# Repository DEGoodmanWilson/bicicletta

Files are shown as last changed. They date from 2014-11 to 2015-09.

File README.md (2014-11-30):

BICICLETTA
==========

Bicicletta is an open source iOS / Android interface for your electric bicycle.

You can read more about this project on the project's [Github Page](http://degoodmanwilson.github.io/bicicletta/)

FIRMWARE LICENSE
================

Copyright © D.E. Goodman-Wilson 2014.

Bicicletta Firmware is free software: you can redistribute it and/or modify
it under the terms of the GNU General Public License as published by
the Free Software Foundation, either version 3 of the License, or
(at your option) any later version.

This program is distributed in the hope that it will be useful,
but WITHOUT ANY WARRANTY; without even the implied warranty of
MERCHANTABILITY or FITNESS FOR A PARTICULAR PURPOSE.  See the
GNU General Public License for more details.

You should have received a copy of the GNU General Public License
along with Bicicletta Firmware.  If not, see <http://www.gnu.org/licenses/>.

The full text of the license is available in /firmware/LICENSE.txt

HARDWARE LICENSE
================

Copyright © D.E. Goodman-Wilson 2014.

This documentation describes Open Hardware and is licensed under the
CERN OHL v. 1.2.

You may redistribute and modify this documentation under the terms of the
CERN OHL v.1.2. (http://ohwr.org/cernohl). This documentation is distributed
WITHOUT ANY EXPRESS OR IMPLIED WARRANTY, INCLUDING OF
MERCHANTABILITY, SATISFACTORY QUALITY AND FITNESS FOR A
PARTICULAR PURPOSE. Please see the CERN OHL v.1.2 for applicable
conditions.

The full text of the license is available in /hardware/LICENSE.txt

You can read more about how the CERN OHL license applies to this project [on the CERN website](http://www.ohwr.org/attachments/2392/cern_ohl_v_1_2_howto.pdf).

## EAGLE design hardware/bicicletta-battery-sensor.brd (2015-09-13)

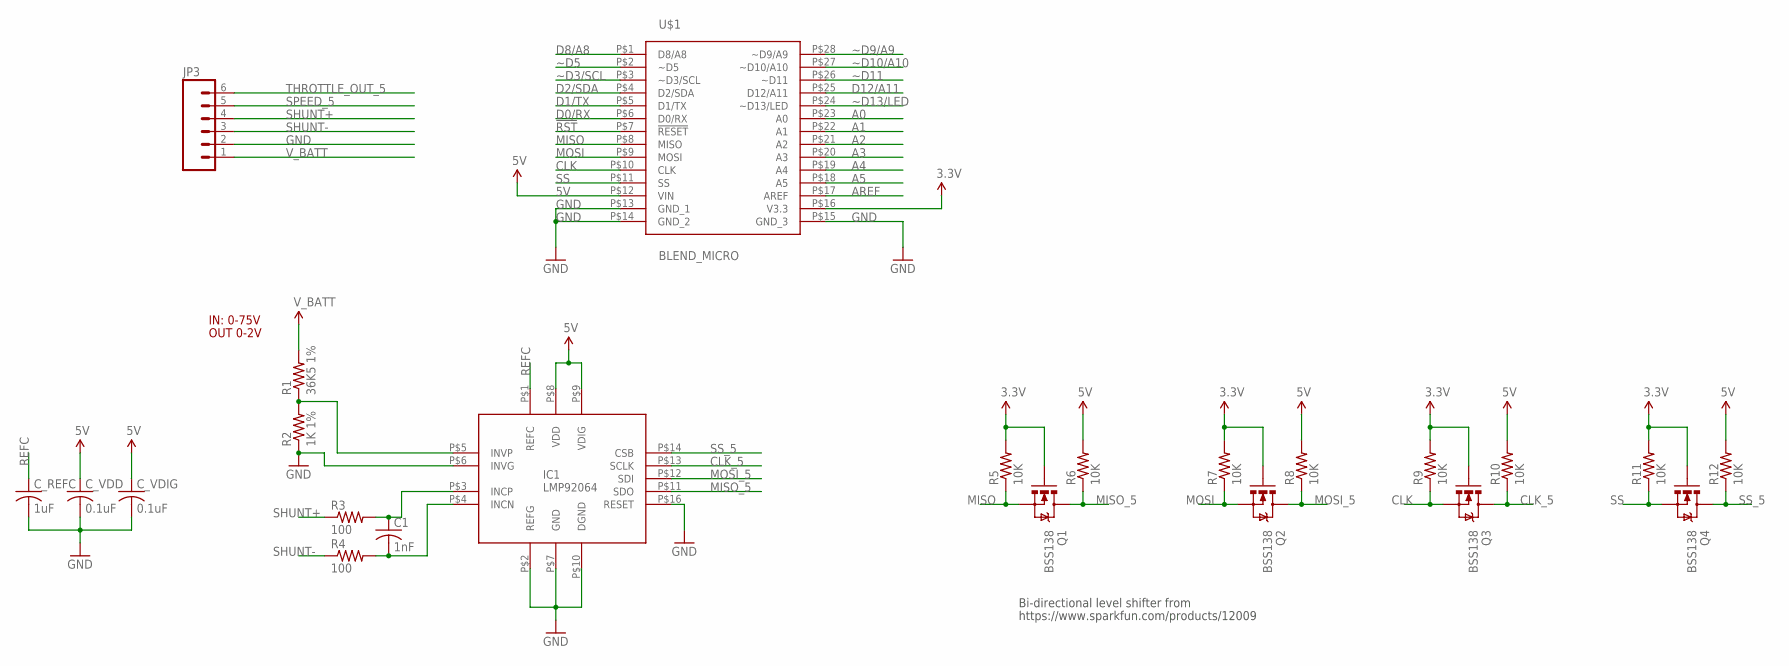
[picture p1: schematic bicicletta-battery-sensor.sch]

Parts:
C1: 1nF; C0603
C_REFC: 1uF; C0603
C_VDD: 0.1uF; C0603
C_VDIG: 0.1uF; C0603
IC1: LMP92064; WSON-16
JP3: M06SIP; 1X06
Q1, Q2, Q3, Q4: BSS138; SOT23-3
R1: 36K5 1%; R0603
R2: 1K 1%; R0603
R3, R4: 100; R0603
R5, R6, R7, R8, R9, R10, R11, R12: 10K; R0603
U$1: BLEND_MICRO

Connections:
3.3V: Q1.1 (G), Q2.1 (G), Q3.1 (G), Q4.1 (G), R5.2, R7.2, R9.2, R11.2, U$1.P$16 (V3.3)
5V: C_VDD.1, C_VDIG.1, IC1.P$8 (VDD), IC1.P$9 (VDIG), R6.2, R8.2, R10.2, R12.2, U$1.P$12 (VIN)
!RST: U$1.P$7 (!RESET)
A0: U$1.P$23 (A0)
A1: U$1.P$22 (A1)
A2: U$1.P$21 (A2)
A3: U$1.P$20 (A3)
A4: U$1.P$19 (A4)
A5: U$1.P$18 (A5)
AREF: U$1.P$17 (AREF)
CLK: Q3.2 (S), R9.1, U$1.P$10 (CLK)
CLK_5: IC1.P$13 (SCLK), Q3.3 (D), R10.1
D0/RX: U$1.P$6 (D0/RX)
D1/TX: U$1.P$5 (D1/TX)
D2/SDA: U$1.P$4 (D2/SDA)
D8/A8: U$1.P$1 (D8/A8)
D12/A11: U$1.P$25 (D12/A11)
GND: C_REFC.2, C_VDD.2, C_VDIG.2, IC1.P$2 (REFG), IC1.P$6 (INVG), IC1.P$7 (GND), IC1.P$10 (DGND), IC1.P$16 (RESET), JP3.2, R2.1, U$1.P$13 (GND_1), U$1.P$14 (GND_2), U$1.P$15 (GND_3)
MISO: Q1.2 (S), R5.1, U$1.P$8 (MISO)
MISO_5: IC1.P$11 (SDO), Q1.3 (D), R6.1
MOSI: Q2.2 (S), R7.1, U$1.P$9 (MOSI)
MOSI_5: IC1.P$12 (SDI), Q2.3 (D), R8.1
unnamed: IC1.P$5 (INVP), R1.1, R2.2
unnamed: C1.1, IC1.P$3 (INCP), R3.2
unnamed: C1.2, IC1.P$4 (INCN), R4.2
REFC: C_REFC.1, IC1.P$1 (REFC)
SHUNT+: JP3.4, R3.1
SHUNT-: JP3.3, R4.1
SPEED_5: JP3.5
SS: Q4.2 (S), R11.1, U$1.P$11 (SS)
SS_5: IC1.P$14 (CSB), Q4.3 (D), R12.1
THROTTLE_OUT_5: JP3.6
V_BATT: JP3.1, R1.2
~D3/SCL: U$1.P$3 (~D3/SCL)
~D5: U$1.P$2 (~D5)
~D9/A9: U$1.P$28 (~D9/A9)
~D10/A10: U$1.P$27 (~D10/A10)
~D11: U$1.P$26 (~D11)
~D13/LED: U$1.P$24 (~D13/LED)

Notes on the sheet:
IN: 0-75V
OUT 0-2V
Bi-directional level shifter from
https://www.sparkfun.com/products/12009

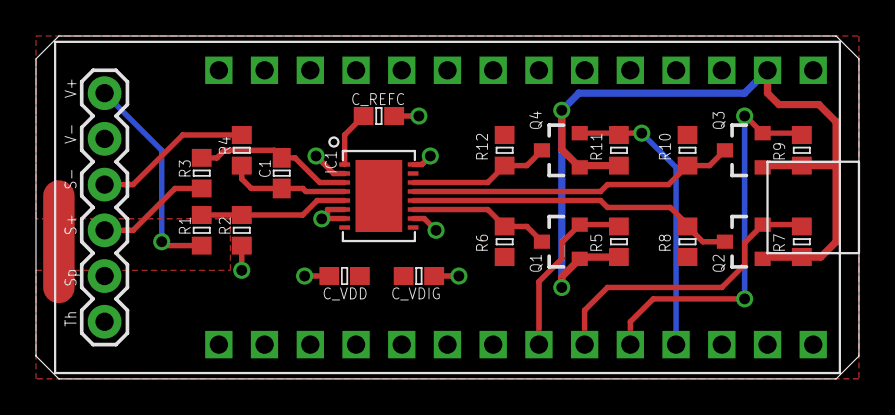
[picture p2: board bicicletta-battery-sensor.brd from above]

Board: 2 copper layers, 45.7 x 19.1 mm, 24 parts (1 on the bottom side), 18 nets.

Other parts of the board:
U$2: RAILSTARS_25MM

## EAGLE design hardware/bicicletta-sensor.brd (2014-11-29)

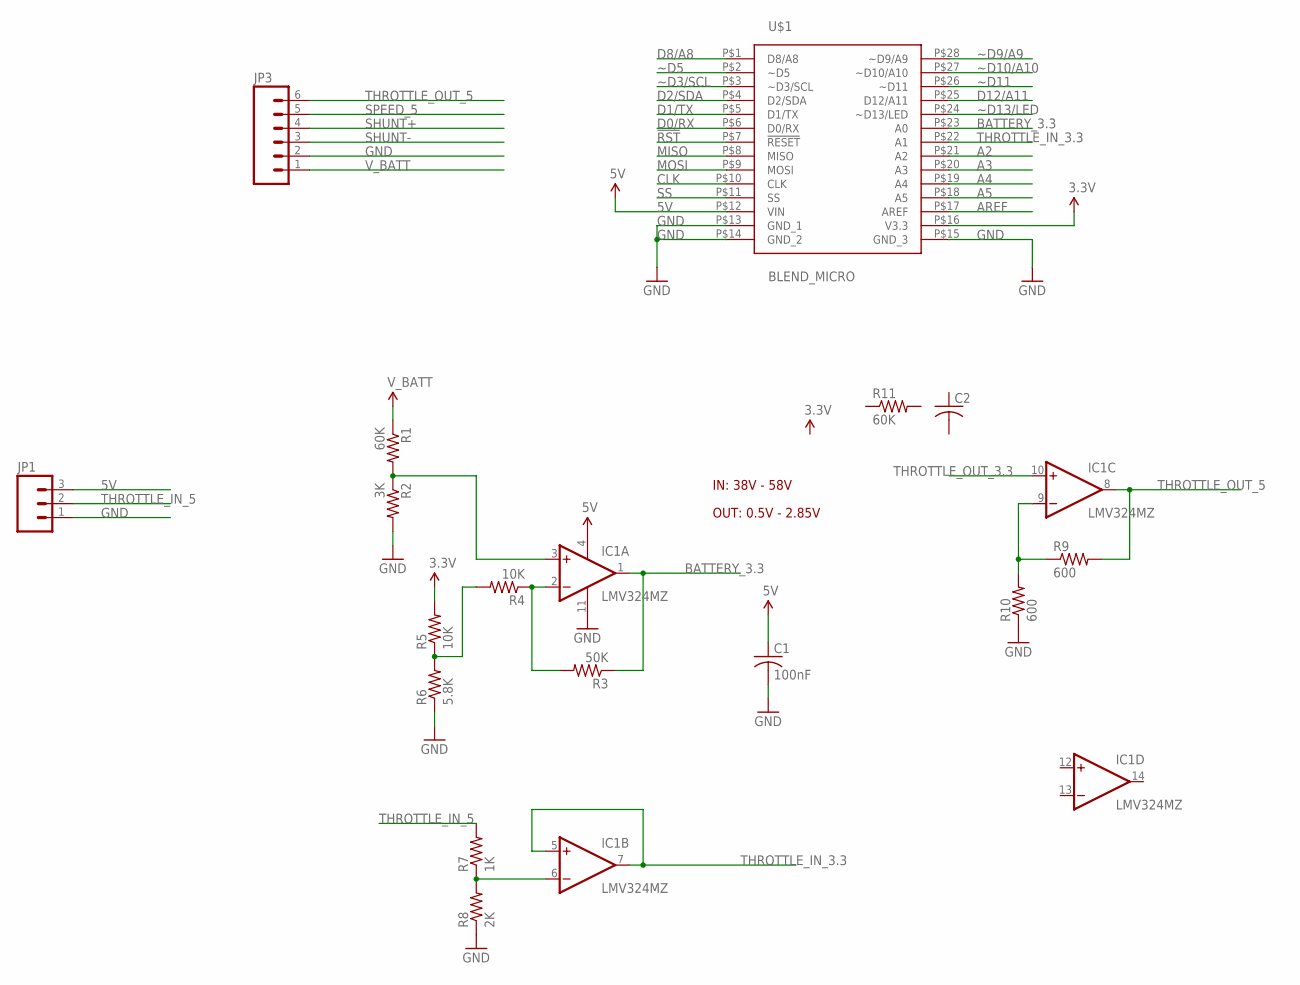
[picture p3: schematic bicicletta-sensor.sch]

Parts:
C1: 100nF; C0603
C2: C-USC0603; C0603
IC1: LMV324MZ; TSSOP14
JP1: M03PTH; 1X03
JP3: M06SIP; 1X06
R1, R11: 60K; R0603
R2: 3K; R0603
R3: 50K; R0603
R4, R5: 10K; R0603
R6: 5.8K; R0603
R7: 1K; R0603
R8: 2K; R0603
R9, R10: 600; R0603
U$1: BLEND_MICRO

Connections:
3.3V: R5.2, U$1.P$16 (V3.3)
5V: C1.1, IC1.4 (V+), JP1.3, U$1.P$12 (VIN)
!RST: U$1.P$7 (!RESET)
A2: U$1.P$21 (A2)
A3: U$1.P$20 (A3)
A4: U$1.P$19 (A4)
A5: U$1.P$18 (A5)
AREF: U$1.P$17 (AREF)
BATTERY_3.3: IC1.1 (OUT), R3.1, U$1.P$23 (A0)
BIAS: R4.2, R5.1, R6.2
CLK: U$1.P$10 (CLK)
D0/RX: U$1.P$6 (D0/RX)
D1/TX: U$1.P$5 (D1/TX)
D2/SDA: U$1.P$4 (D2/SDA)
D8/A8: U$1.P$1 (D8/A8)
D12/A11: U$1.P$25 (D12/A11)
GND: C1.2, IC1.11 (V-), JP1.1, JP3.2, R2.2, R6.1, R8.1, R10.1, U$1.P$13 (GND_1), U$1.P$14 (GND_2), U$1.P$15 (GND_3)
MISO: U$1.P$8 (MISO)
MOSI: U$1.P$9 (MOSI)
unnamed: IC1.9 (-IN), R9.1, R10.2
unnamed: IC1.3 (+IN), R1.2, R2.1
unnamed: IC1.2 (-IN), R3.2, R4.1
unnamed: IC1.6 (-IN), R7.1, R8.2
SHUNT+: JP3.4
SHUNT-: JP3.3
SPEED_5: JP3.5
SS: U$1.P$11 (SS)
THROTTLE_IN_3.3: IC1.5 (+IN), IC1.7 (OUT), U$1.P$22 (A1)
THROTTLE_IN_5: JP1.2, R7.2
THROTTLE_OUT_3.3: IC1.10 (+IN)
THROTTLE_OUT_5: IC1.8 (OUT), JP3.6, R9.2
V_BATT: JP3.1, R1.1
~D3/SCL: U$1.P$3 (~D3/SCL)
~D5: U$1.P$2 (~D5)
~D9/A9: U$1.P$28 (~D9/A9)
~D10/A10: U$1.P$27 (~D10/A10)
~D11: U$1.P$26 (~D11)
~D13/LED: U$1.P$24 (~D13/LED)

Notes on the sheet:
IN: 38V - 58V
OUT: 0.5V - 2.85V

Board: 2 copper layers, 18 parts (1 on the bottom side), 13 nets, no tracks yet.

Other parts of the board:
U$2: RAILSTARS_25MM

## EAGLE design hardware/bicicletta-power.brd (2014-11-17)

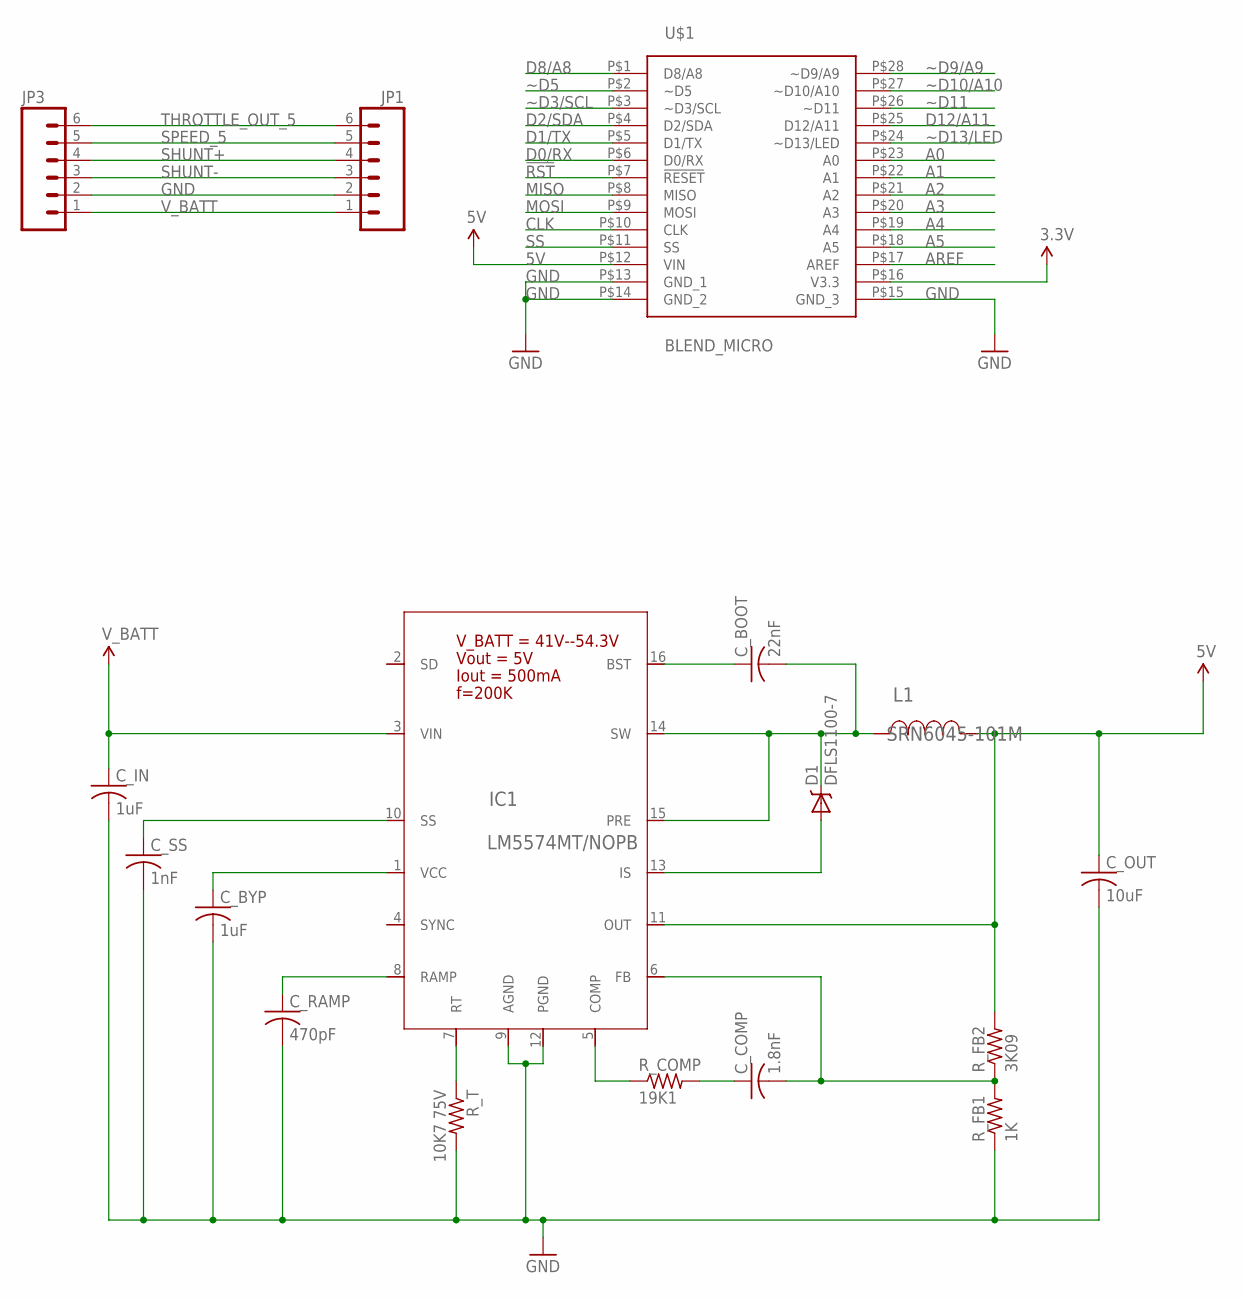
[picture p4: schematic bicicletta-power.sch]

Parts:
C_BOOT: 22nF; C0603
C_BYP: 1uF; C0603
C_COMP: 1.8nF; C0603
C_IN: 1uF; C1206
C_OUT: 10uF; C0805
C_RAMP: 470pF; C0603
C_SS: 1nF; C0603
D1: DFLS1100-7; POWERDI123
IC1: LM5574MT/NOPB; MTC16
JP1, JP3: M06SIP; 1X06
L1: SRN6045-101M; SRN6045
R_COMP: 19K1; R0603
R_FB1: 1K; R0603
R_FB2: 3K09; R0603
R_T: 10K7 75V; R0603
U$1: BLEND_MICRO

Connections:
3.3V: U$1.P$16 (V3.3)
5V: C_OUT.1, IC1.11 (OUT), L1.2, R_FB2.2, U$1.P$12 (VIN)
!RST: U$1.P$7 (!RESET)
A0: U$1.P$23 (A0)
A1: U$1.P$22 (A1)
A2: U$1.P$21 (A2)
A3: U$1.P$20 (A3)
A4: U$1.P$19 (A4)
A5: U$1.P$18 (A5)
AREF: U$1.P$17 (AREF)
CLK: U$1.P$10 (CLK)
D0/RX: U$1.P$6 (D0/RX)
D1/TX: U$1.P$5 (D1/TX)
D2/SDA: U$1.P$4 (D2/SDA)
D8/A8: U$1.P$1 (D8/A8)
D12/A11: U$1.P$25 (D12/A11)
GND: C_BYP.2, C_IN.2, C_OUT.2, C_RAMP.2, C_SS.2, IC1.9 (AGND), IC1.12 (PGND), JP1.2, JP3.2, R_FB1.1, R_T.2, U$1.P$13 (GND_1), U$1.P$14 (GND_2), U$1.P$15 (GND_3)
MISO: U$1.P$8 (MISO)
MOSI: U$1.P$9 (MOSI)
unnamed: C_SS.1, IC1.10 (SS)
unnamed: C_BYP.1, IC1.1 (VCC)
unnamed: C_RAMP.1, IC1.8 (RAMP)
unnamed: IC1.7 (RT), R_T.1
unnamed: C_COMP.2, IC1.6 (FB), R_FB1.2, R_FB2.1
unnamed: C_COMP.1, R_COMP.2
unnamed: IC1.5 (COMP), R_COMP.1
unnamed: D1.A, IC1.13 (IS)
unnamed: C_BOOT.1, IC1.16 (BST)
unnamed: C_BOOT.2, D1.K, IC1.14 (SW), IC1.15 (PRE), L1.1
SHUNT+: JP1.4, JP3.4
SHUNT-: JP1.3, JP3.3
SPEED_5: JP1.5, JP3.5
SS: U$1.P$11 (SS)
THROTTLE_OUT_5: JP1.6, JP3.6
V_BATT: C_IN.1, IC1.3 (VIN), JP1.1, JP3.1
~D3/SCL: U$1.P$3 (~D3/SCL)
~D5: U$1.P$2 (~D5)
~D9/A9: U$1.P$28 (~D9/A9)
~D10/A10: U$1.P$27 (~D10/A10)
~D11: U$1.P$26 (~D11)
~D13/LED: U$1.P$24 (~D13/LED)

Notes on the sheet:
f=200K
V_BATT = 41V--54.3V
Vout = 5V
Iout = 500mA

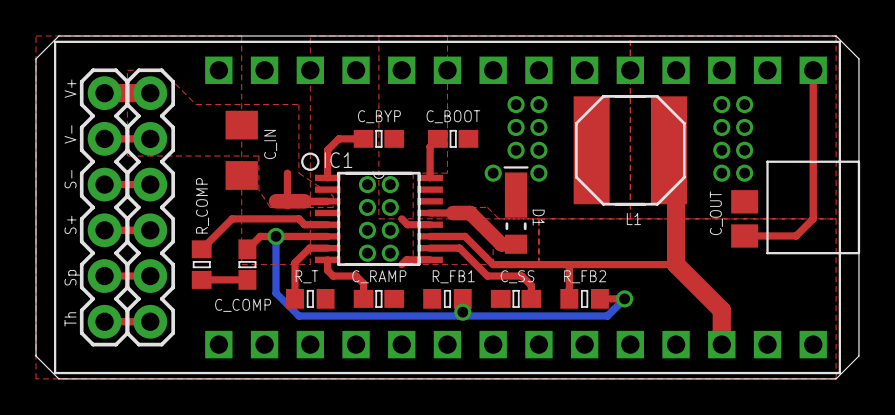
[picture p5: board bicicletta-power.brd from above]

Board: 2 copper layers, 45.7 x 19.1 mm, 18 parts (1 on the bottom side), 17 nets.

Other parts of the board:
U$2: RAILSTARS_25MM

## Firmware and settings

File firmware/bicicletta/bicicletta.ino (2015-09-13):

#include <aci.h>
#include <aci_cmds.h>
#include <aci_evts.h>
#include <aci_protocol_defines.h>
#include <aci_queue.h>
#include <acilib.h>
#include <acilib_defs.h>
#include <acilib_if.h>
#include <acilib_types.h>
#include <ble_assert.h>
#include <boards.h>
#include <dtm.h>
#include <hal_aci_tl.h>
#include <hal_platform.h>
#include <lib_aci.h>
#include <aci_setup.h>

#include <RBL_nRF8001.h>

#include <SPI.h>

#include "bicicletta.h"
#include "rs_ble.h"
#include "battery.h"

void setup(void) {
  Serial.begin(57600);

  //Initialize BLE
  rs_ble_init();

  //Initialize SPI communication with battery power IC
  battery_init();
}

void loop(void) {
  rs_ble_process();
  battery_process();
}

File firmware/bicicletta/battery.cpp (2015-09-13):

//ble_busy is the key func to check
#include "battery.h"
#include <RBL_nRF8001.h>

void battery_init(void)
{
  SPI.begin();
  
  SPI.setDataMode(SPI_MODE1);
  SPI.setBitOrder(MSBFIRST);
}

void battery_process(void)
{
  if(ble_busy()) { return; }
  uint8_t val1, val2, val3, val4;
  
  digitalWrite(13, LOW);
  SPI.transfer(0x80);
  SPI.transfer(0x0C);
  val1 = SPI.transfer(0x00); //read it back out
  digitalWrite(13, HIGH);
  
  digitalWrite(13, LOW);
  SPI.transfer(0x80);
  SPI.transfer(0x0D);
  val2 = SPI.transfer(0x00); //read it back out
  digitalWrite(13, HIGH);
  
//  digitalWrite(13, LOW);
//  SPI.transfer(0x82);
//  SPI.transfer(0x01);
//  val3 = SPI.transfer(0x00); //read it back out
//  digitalWrite(13, HIGH);
//  
//  digitalWrite(13, LOW);
//  SPI.transfer(0x82);
//  SPI.transfer(0x00);
//  val4 = SPI.transfer(0x00); //read it back out
//  digitalWrite(13, HIGH);
  
  Serial.println(val1);
  Serial.println(val2);
//  Serial.println(val3);
//  Serial.println(val4);
  Serial.println("###");
}

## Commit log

2014-08-10 BLEduino in schematic.
    [bicicletta.sch]
2014-08-28 Switching regulator is set up in schematic.
    [bicicletta.sch]
2014-09-02 Added 3.3V LDO regulator
    [bicicletta.sch]
2014-09-02 Added analog voltage shifter of dubious quality. WOrks in simulation
    [bicicletta.sch]
2014-09-02 Here is the circuit.jar design for the analog level-shifter.
2014-09-02 Oh wait, this isn't for the throttle, this is for level-shifting the battery input. The input is scaled from 38-58V to 0-3.3V. Roughly.
    [bicicletta.sch]
2014-09-02 Fixed battery voltage shifter, added level shifter for throttle (5V hall effect sensor)
    [bicicletta.sch]
2014-09-03 Refactored the ripple feedback circuit on the switching regulator
    [bicicletta.sch]
2014-09-04 Beginning to refactor design into stackable modules.
    [bicicletta-power.sch]
2014-09-04 Adding connectors.
    [bicicletta-power.sch]
2014-09-04 Error in regulator connections. Please double check
    [bicicletta-power.sch]
2014-09-04 Adding PCB layout.
    [bicicletta-power.brd, bicicletta-power.sch]
2014-09-05 Close to final layout on switching regulator.
    [bicicletta-power.brd]
2014-09-05 Fine tuning
    [bicicletta-power.brd]
2014-09-05 Updated to include actual component for the BLEND MICRO
    [bicicletta-power.brd, bicicletta-power.sch]
2014-09-06 Wider voltage range on the op-amp level shifter, refinements on the PCB layout
    [bicicletta-power.brd]
2014-09-08 Rethinking the PCB layout to be more compact.
    [bicicletta-power.brd, bicicletta-power.sch]
2014-09-08 More compact still. Need to check solderability.
    [bicicletta-power.brd]
2014-09-09 Layout of switching regulator is nearing finalization.
    [bicicletta-power.brd]
2014-09-09 First final draft of PCB layout. Requires validation.
    [bicicletta-power.brd]
2014-09-09 Inductor speced out. PCB placement getting closer.
    [bicicletta-power.brd, bicicletta-power.sch]
2014-09-19 SMall tweaks that add up.
    [bicicletta-power.brd, bicicletta-power.sch]
2014-09-19 HULK SMASH!
    [bicicletta-power.brd]
2014-09-19 labels cleaned up
    [bicicletta-power.brd]
2014-09-20 Futzing with the ground planes and via tenting.
    [bicicletta-power.brd]
2014-09-29 To hell with the buck regulator, let's just take 5V from the controller.
    [bicicletta-power.brd, bicicletta-power.sch]
2014-09-30 Revert "To hell with the buck regulator, let's just take 5V from the controller."
    This reverts commit f16ee5c0247fff79c0027ea9109af273bc1d2e81.
    [bicicletta-power.brd, bicicletta-power.sch]
2014-10-08 Why not use the Blend's 150mA 3.3V regulator?
    [bicicletta-power.brd, bicicletta-power.sch]
2014-11-12 There it is. Order that.
    [bicicletta-power.brd, bicicletta-power.sch]
2014-11-17 Final silkscreen
    [bicicletta-power.brd]
2014-11-17 Empty sensor boards.
    [bicicletta-sensor.brd, bicicletta-sensor.sch]
2014-11-20 Better analog design. Still working on DAC for throttle output.
    [bicicletta-sensor.brd, bicicletta-sensor.sch]
2014-11-29 Unsure what all has changed…
    [bicicletta-sensor.brd, bicicletta-sensor.sch]
2014-12-03 Let's use the LMP92064!
    [bicicletta-battery-sensor.brd, bicicletta-battery-sensor.sch, bicicletta.sch]
2014-12-03 Add level shifter
    [bicicletta-battery-sensor.brd, bicicletta-battery-sensor.sch]
2014-12-03 preliminary routing of voltage and current sense PCB
    [bicicletta-battery-sensor.brd]
2014-12-03 Nearly finalized PCB for battery sensor module
    [bicicletta-battery-sensor.brd, bicicletta-battery-sensor.sch]
2014-12-03 Add value to the TXB0108
    [bicicletta-battery-sensor.brd, bicicletta-battery-sensor.sch]
2014-12-04 A little more space on the resistors for ease of soldering
    [bicicletta-battery-sensor.brd]
2014-12-04 Update timestamp on sensor PCB
    [bicicletta-battery-sensor.brd]
2015-09-13 Trying out a new level shifter, as the previous integrated one proved awfully fiddly in practice.
    [bicicletta-battery-sensor.brd, bicicletta-battery-sensor.sch]
2015-09-13 Tidying some traces up.
    [bicicletta-battery-sensor.brd]

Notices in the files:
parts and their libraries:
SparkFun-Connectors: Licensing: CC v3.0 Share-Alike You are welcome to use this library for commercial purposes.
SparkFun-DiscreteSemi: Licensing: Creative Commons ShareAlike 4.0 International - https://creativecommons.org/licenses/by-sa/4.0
